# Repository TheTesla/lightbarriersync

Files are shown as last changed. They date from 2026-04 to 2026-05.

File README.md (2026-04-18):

# Light Barrier Synchronous

This is a robust continuous wave modulated light barrier with a synchronous detector. The sensitivity is very low against other modulated ligth sources. All electrical interfaces are protected against reverse polarity, over voltage and over current.

It contains only easily available discrete standard components and the board has only one solder side.

## Technical Data

| Parameter | Min | Typ | Max | Unit |
| --- | --- | --- | --- | ---- |
| Operating Voltage | 3.3 | 5 |  35 | V |
| Current Consumption | | |  10 | mA |
| Output Sink Current | | | 800 | uA |
| Temperature Range | 0 | |  70 | °C |
| Carrier Frequency | | 7 | |  kHz |

## Pictures

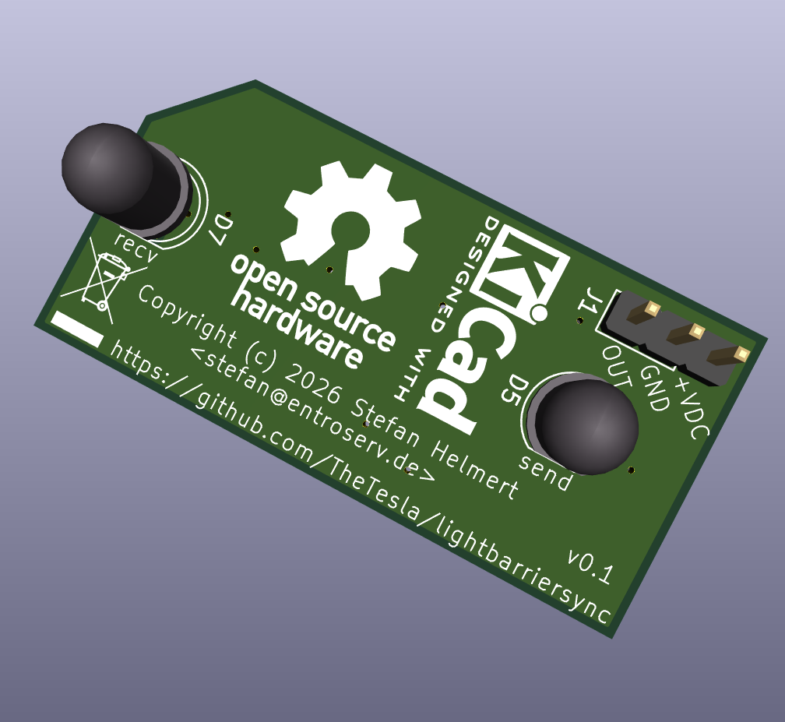
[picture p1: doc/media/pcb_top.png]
Rendering: Top side of the PCB


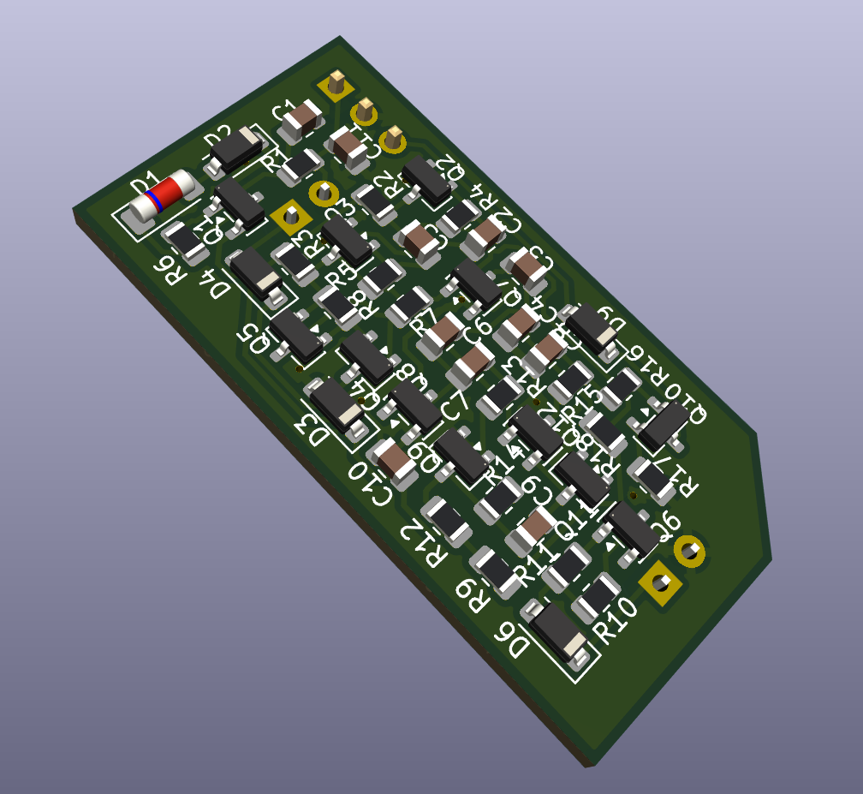
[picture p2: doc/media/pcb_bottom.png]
Rendering: Bottom side of the PCB


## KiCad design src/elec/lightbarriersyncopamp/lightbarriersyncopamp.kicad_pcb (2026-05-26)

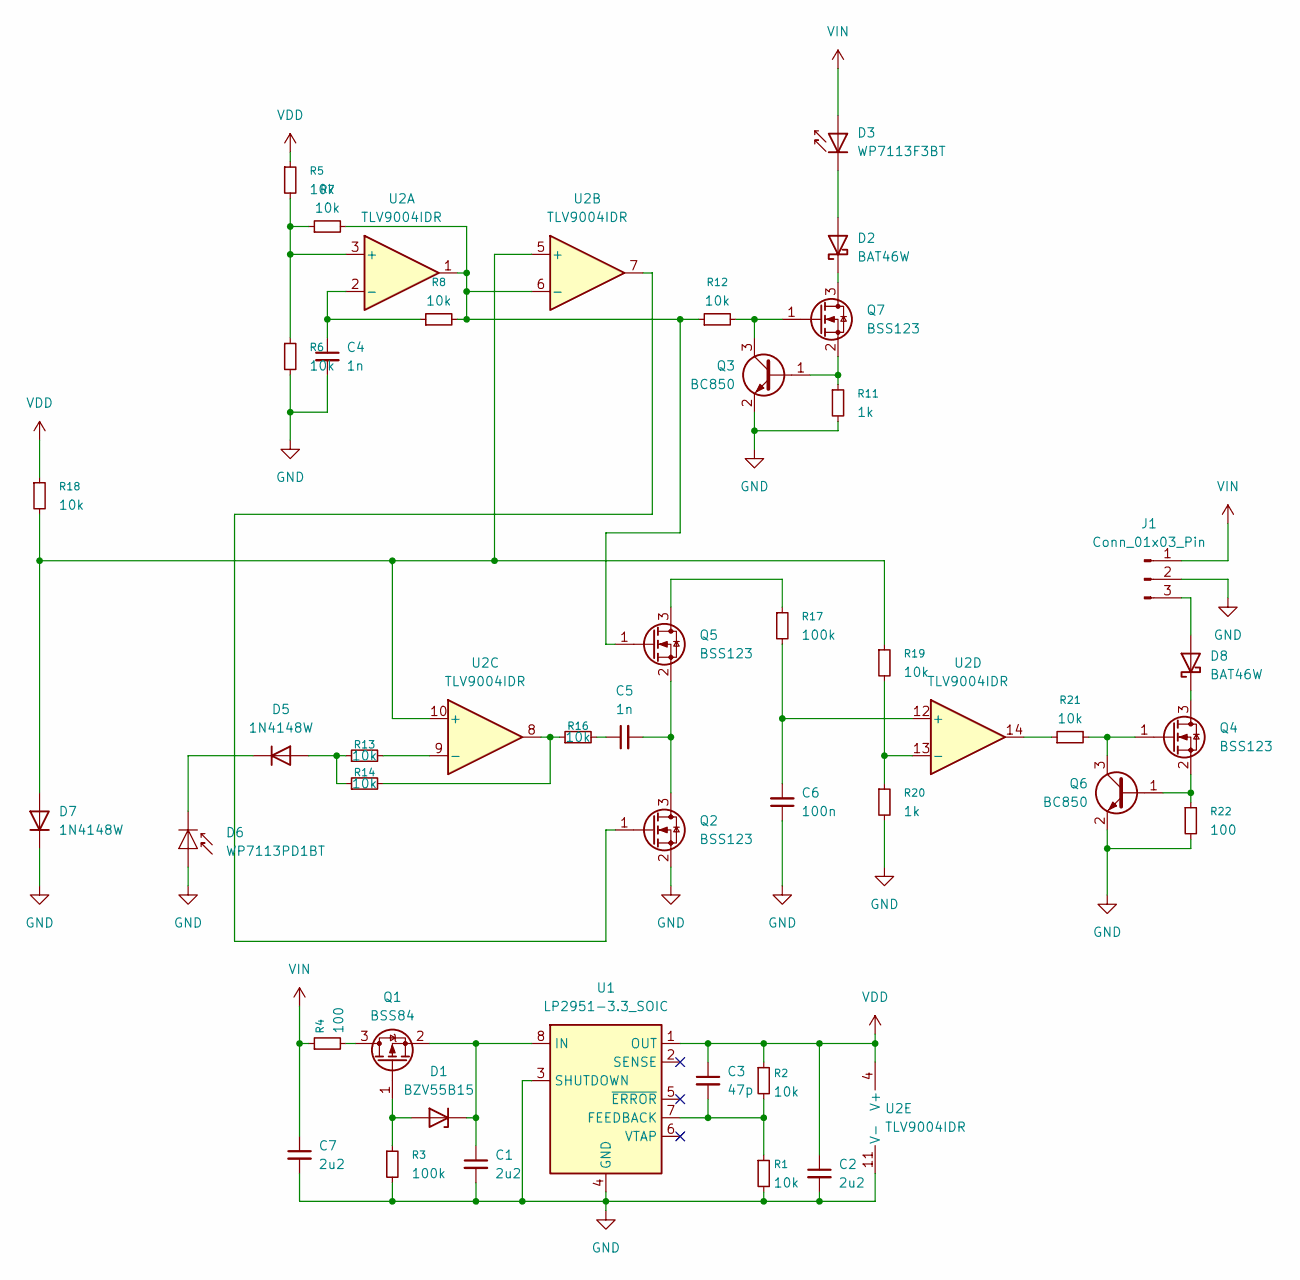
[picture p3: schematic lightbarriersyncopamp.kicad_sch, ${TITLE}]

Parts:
C1, C2, C7: 2u2; C_0805_2012Metric
C3: 47p; C_0805_2012Metric
C4, C5: 1n; C_0805_2012Metric
C6: 100n; C_0805_2012Metric
D1: BZV55B15; D_MiniMELF
D2, D8: BAT46W; D_SOD-123
D3: WP7113F3BT; LED_D5.0mm_IRGrey
D5, D7: 1N4148W; D_SOD-123
D6: WP7113PD1BT; LED_D5.0mm_IRGrey
J1: Conn_01x03_Pin; PinHeader_1x03_P2.54mm_Vertical
Q1: BSS84; SOT-23
Q2, Q4, Q5, Q7: BSS123; SOT-23
Q3, Q6: BC850; SOT-23
R1, R2, R5, R6, R7, R8, R12, R13, R14, R16, R18, R19, R21: 10k; R_0805_2012Metric
R3, R17: 100k; R_0805_2012Metric
R4, R22: 100; R_0805_2012Metric
R11, R20: 1k; R_0805_2012Metric
U1: LP2951-3.3_SOIC; SOIC-8_3.9x4.9mm_P1.27mm
U2: TLV9004IDR; SOIC-14_3.9x8.7mm_P1.27mm

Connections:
GND: C1.2, C2.2, C4.2, C6.1, C7.2, D6.2 (A), D7.1 (K), J1.2, Q2.2 (S), Q3.2 (E), Q6.2 (E), R1.2, R3.2, R6.2, R11.2, R20.2, R22.2, U1.3 (SHUTDOWN), U1.4 (GND), U2.11 (V-)
unnamed: C5.1, R16.2
unnamed: D1.2 (A), Q1.1 (G), R3.1
unnamed: C1.1, D1.1 (K), Q1.2 (S), U1.8 (IN)
unnamed: D2.2 (A), D3.1 (K)
unnamed: D2.1 (K), Q7.3 (D)
unnamed: D5.2 (A), R13.1, R14.1
unnamed: D5.1 (K), D6.1 (K)
unnamed: D7.2 (A), R18.2, R19.1, U2.5 (+), U2.10 (+)
unnamed: D8.2 (A), J1.3
unnamed: D8.1 (K), Q4.3 (D)
unnamed: Q1.3 (D), R4.2
unnamed: C5.2, Q2.3 (D), Q5.2 (S)
unnamed: Q2.1 (G), U2.7
unnamed: Q3.1 (B), Q7.2 (S), R11.1
unnamed: Q3.3 (C), Q7.1 (G), R12.2
unnamed: Q4.1 (G), Q6.3 (C), R21.2
unnamed: Q4.2 (S), Q6.1 (B), R22.1
unnamed: Q5.3 (D), R17.1
unnamed: Q5.1 (G), R7.2, R8.2, R12.1, U2.1, U2.6 (-)
unnamed: R14.2, R16.1, U2.8
unnamed: R21.1, U2.14
unnamed: C3.2, R1.1, R2.2, U1.7 (FEEDBACK)
unnamed: R5.2, R6.1, R7.1, U2.3 (+)
unnamed: C4.1, R8.1, U2.2 (-)
unnamed: R13.2, U2.9 (-)
unnamed: C6.2, R17.2, U2.12 (+)
unnamed: R19.2, R20.1, U2.13 (-)
VDD: C2.1, C3.1, R2.1, R5.1, R18.1, U1.1 (OUT), U2.4 (V+)
VIN: C7.1, D3.2 (A), J1.1, R4.1

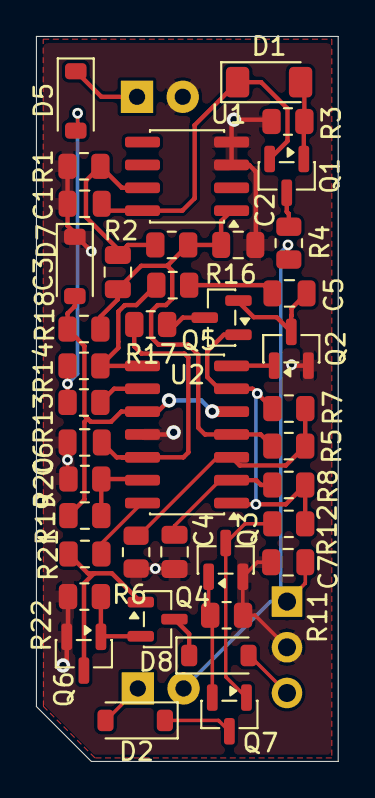
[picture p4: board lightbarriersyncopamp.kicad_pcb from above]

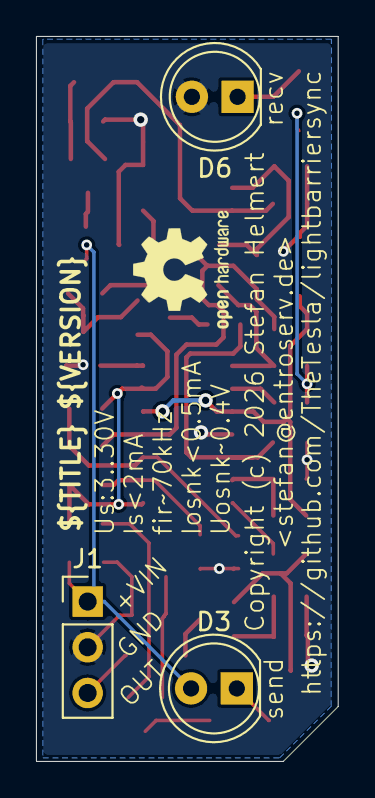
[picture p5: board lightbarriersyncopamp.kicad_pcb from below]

Board: 2 copper layers, 16.8 x 40.3 mm, 43 parts (3 on the bottom side), 30 nets.

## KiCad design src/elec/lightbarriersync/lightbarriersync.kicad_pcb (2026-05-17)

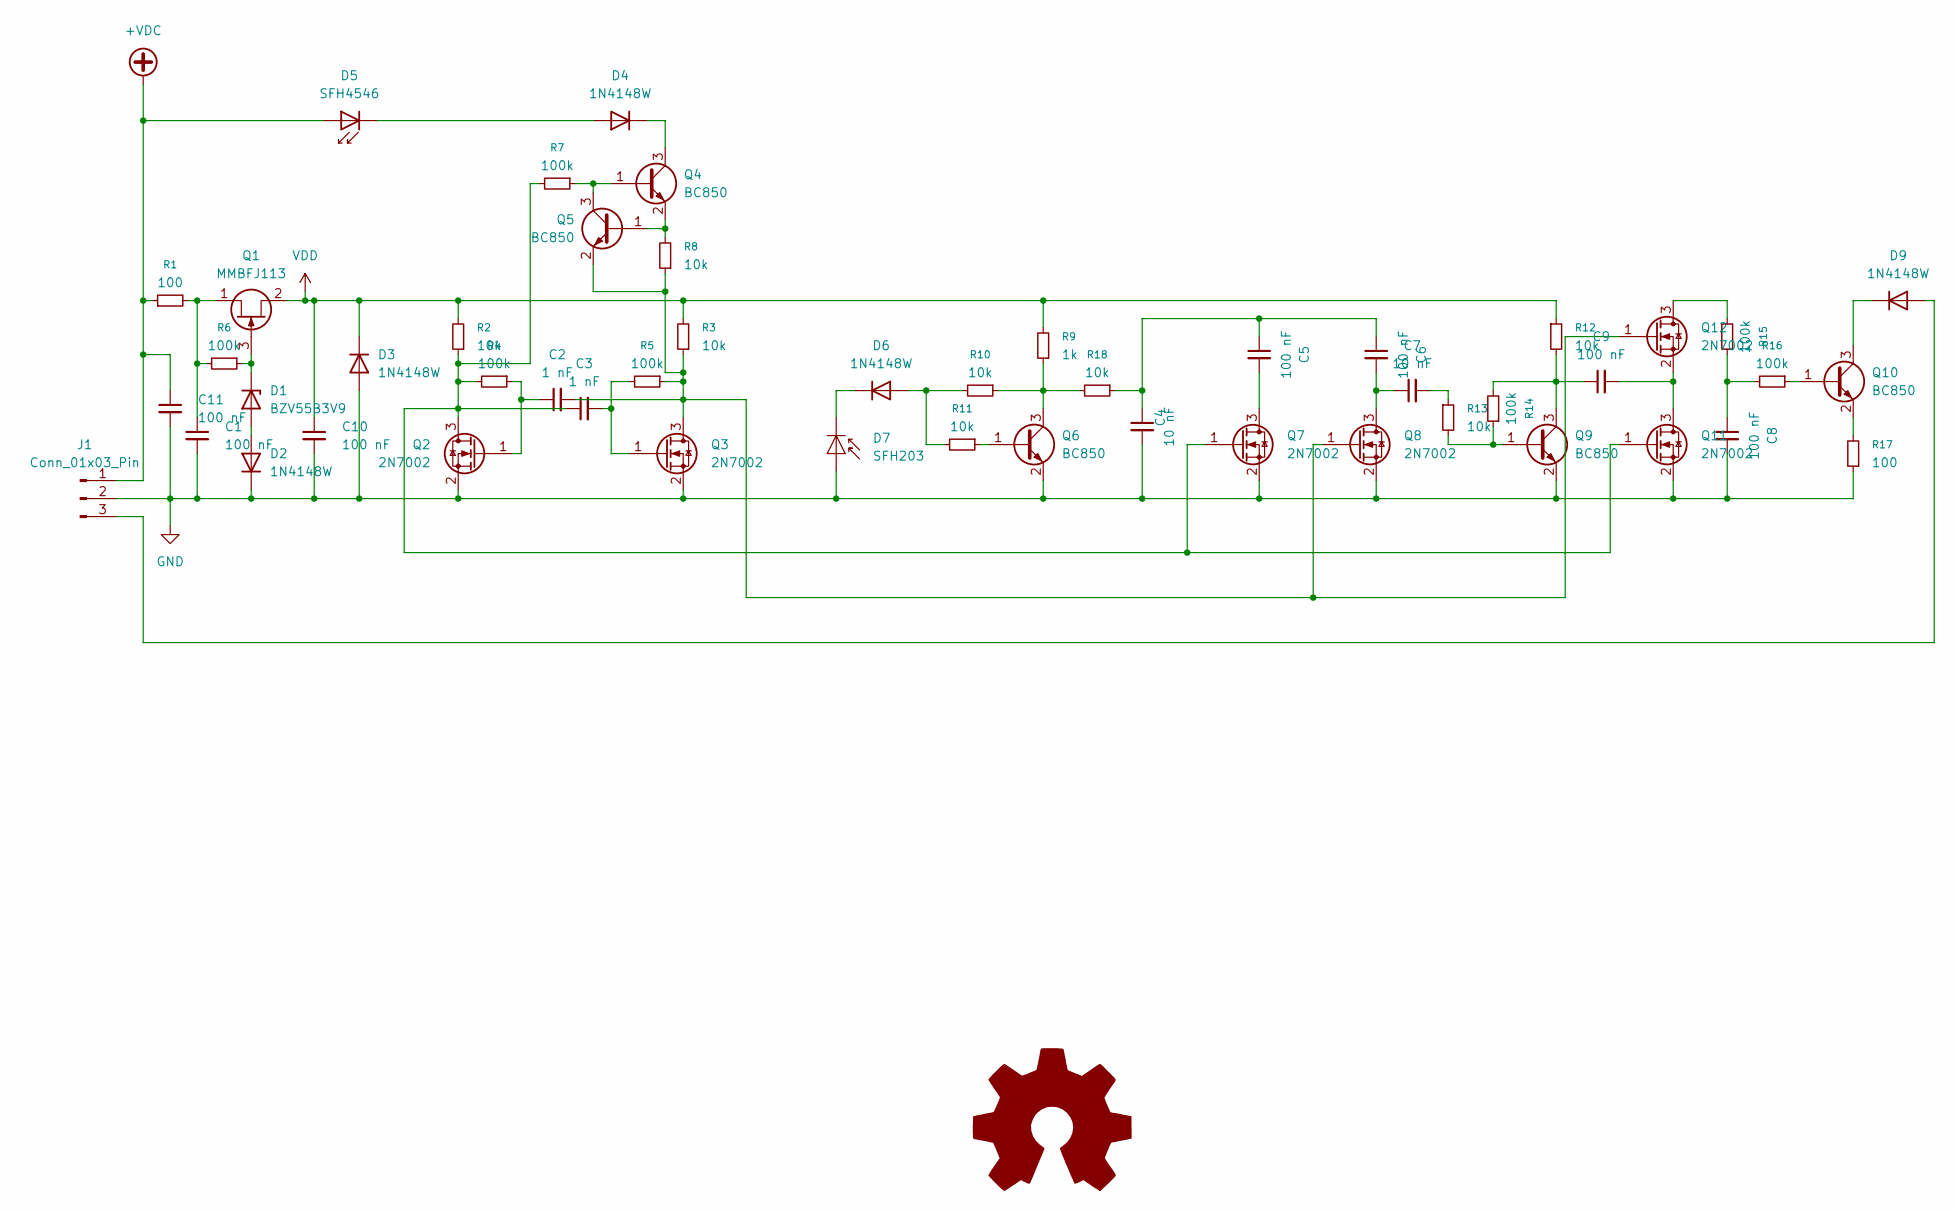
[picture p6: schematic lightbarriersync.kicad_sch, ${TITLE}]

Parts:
C1, C5, C6, C8, C9, C10, C11: 100 nF; C_0805_2012Metric
C2, C3: 1 nF; C_0805_2012Metric
C4, C7: 10 nF; C_0805_2012Metric
D1: BZV55B3V9; D_MiniMELF
D2, D3, D4, D6, D9: 1N4148W; D_SOD-123
D5: SFH4546; LED_D5.0mm_IRGrey
D7: SFH203; LED_D5.0mm_IRGrey
J1: Conn_01x03_Pin; PinHeader_1x03_P2.54mm_Vertical
Q1: MMBFJ113; SOT-23
Q2, Q3, Q7, Q8, Q11, Q12: 2N7002; SOT-23
Q4, Q5, Q6, Q9, Q10: BC850; SOT-23
R1, R17: 100; R_0805_2012Metric
R2, R3, R8, R10, R11, R12, R13, R18: 10k; R_0805_2012Metric
R4, R5, R6, R7, R14, R15, R16: 100k; R_0805_2012Metric
R9: 1k; R_0805_2012Metric

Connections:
+VDC: C11.1, D5.2 (A), J1.1, R1.1
GND: C1.2, C4.2, C8.2, C10.2, C11.2, D2.1 (K), D3.2 (A), D7.2 (A), J1.2, Q2.2 (S), Q3.2 (S), Q6.2 (E), Q7.2 (S), Q8.2 (S), Q9.2 (E), Q11.2 (S), R17.1
unnamed: C4.1, C5.1, C6.1, R18.1
unnamed: C7.2, R13.1
unnamed: C8.1, R15.1, R16.2
unnamed: D1.2 (A), D2.2 (A)
unnamed: D1.1 (K), Q1.3 (G), R6.1
unnamed: D4.2 (A), D5.1 (K)
unnamed: D4.1 (K), Q4.3 (C)
unnamed: D6.2 (A), R10.2, R11.2
unnamed: D6.1 (K), D7.1 (K)
unnamed: D9.2 (A), J1.3
unnamed: D9.1 (K), Q10.3 (C)
unnamed: C1.1, Q1.1 (D), R1.2, R6.2
unnamed: C2.1, Q2.1 (G), R4.1
unnamed: C3.2, Q3.1 (G), R5.2
unnamed: Q4.1 (B), Q5.3 (C), R7.1
unnamed: Q4.2 (E), Q5.1 (B), R8.2
unnamed: Q6.1 (B), R11.1
unnamed: Q6.3 (C), R9.1, R10.1, R18.2
unnamed: C5.2, Q7.3 (D)
unnamed: C6.2, C7.1, Q8.3 (D)
unnamed: Q9.1 (B), R13.2, R14.1
unnamed: C9.1, Q9.3 (C), R12.2, R14.2
unnamed: Q10.1 (B), R16.1
unnamed: Q10.2 (E), R17.2
unnamed: C9.2, Q11.3 (D), Q12.2 (S)
unnamed: C3.1, Q2.3 (D), Q7.1 (G), Q11.1 (G), R2.1, R4.2, R7.2
unnamed: Q12.3 (D), R15.2
unnamed: C2.2, Q3.3 (D), Q5.2 (E), Q8.1 (G), Q12.1 (G), R3.1, R5.1, R8.1
VDD: C10.1, D3.1 (K), Q1.2 (S), R2.2, R3.2, R9.2, R12.1

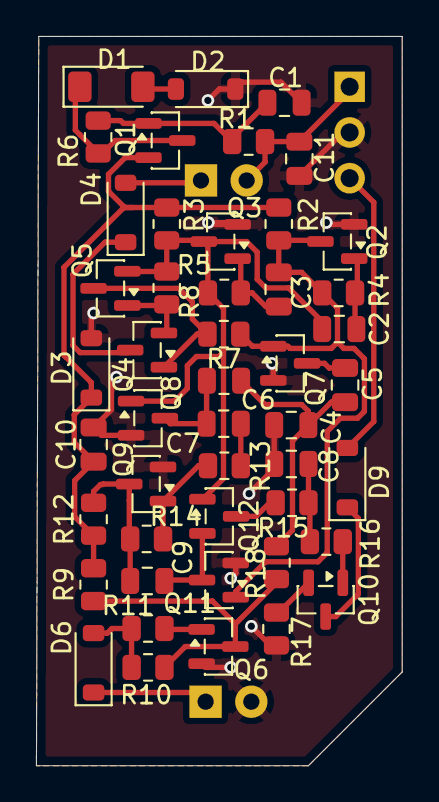
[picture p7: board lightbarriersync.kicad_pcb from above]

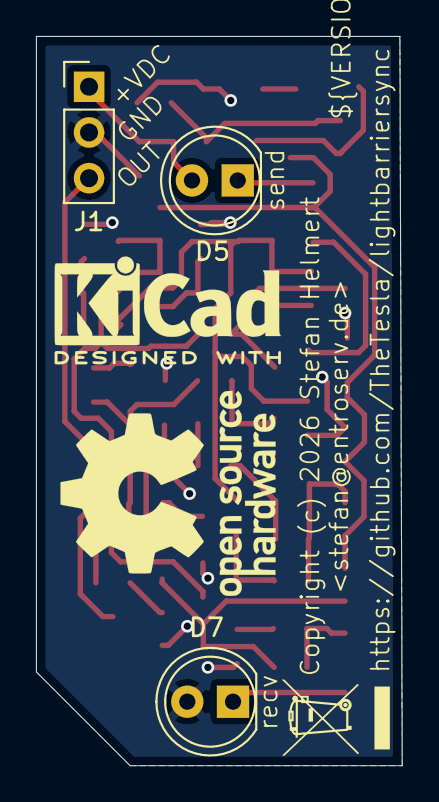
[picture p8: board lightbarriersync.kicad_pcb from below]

Board: 2 copper layers, 20.3 x 40.5 mm, 50 parts (3 on the bottom side), 31 nets.

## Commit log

2026-04-18 PCB nearly ready
    [lightbarriersync.kicad_pcb, lightbarriersync.kicad_sch]
2026-04-18 board ready
    [lightbarriersync.kicad_pcb, lightbarriersync.kicad_sch]
2026-04-18 added simulation file, .gitignore
    [lightbarrier.sch]
2026-05-17 opamp version
    [lightbarriersync.kicad_pcb, lightbarriersyncopamp.kicad_pcb, lightbarriersyncopamp.kicad_sch]
2026-05-17 addec copyright; ToDo: variables, version, opamp variant note, data on silkscreen
    [lightbarriersyncopamp.kicad_pcb]
2026-05-20 ready to build
    [lightbarriersyncopamp.kicad_pcb, lightbarriersyncopamp.kicad_sch]
2026-05-20 minor reference label movement
    [lightbarriersyncopamp.kicad_pcb]
2026-05-26 version 0.2 optimized with less components
    [lightbarriersyncopamp.kicad_pcb, lightbarriersyncopamp.kicad_sch]
2026-05-26 shifted text
    [lightbarriersyncopamp.kicad_pcb]

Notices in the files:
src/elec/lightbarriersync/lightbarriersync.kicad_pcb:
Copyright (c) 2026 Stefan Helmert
